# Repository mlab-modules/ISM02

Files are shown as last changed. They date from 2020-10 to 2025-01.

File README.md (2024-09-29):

# ISM02 - Long Range, Low Power, sub-GHz RF Transceiver

ISM02A is a telemetry module based on the Semtech SX1262 RF transceiver. This module is widely used in LoRa and other sub-GHz wireless communication applications. It incorporates an RF switch (PE4259) to multiplex RX and TX on a single antenna, making it a compact solution for IoT and telemetry use cases.

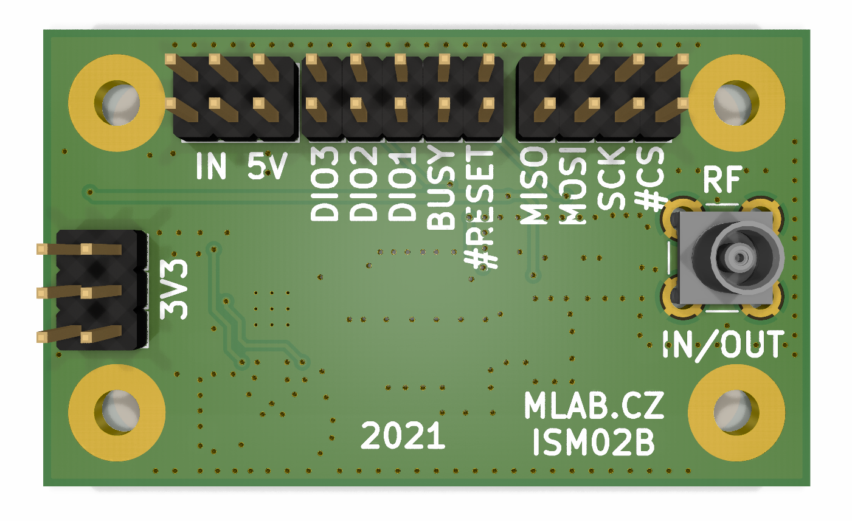
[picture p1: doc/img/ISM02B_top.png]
ISM02A Top

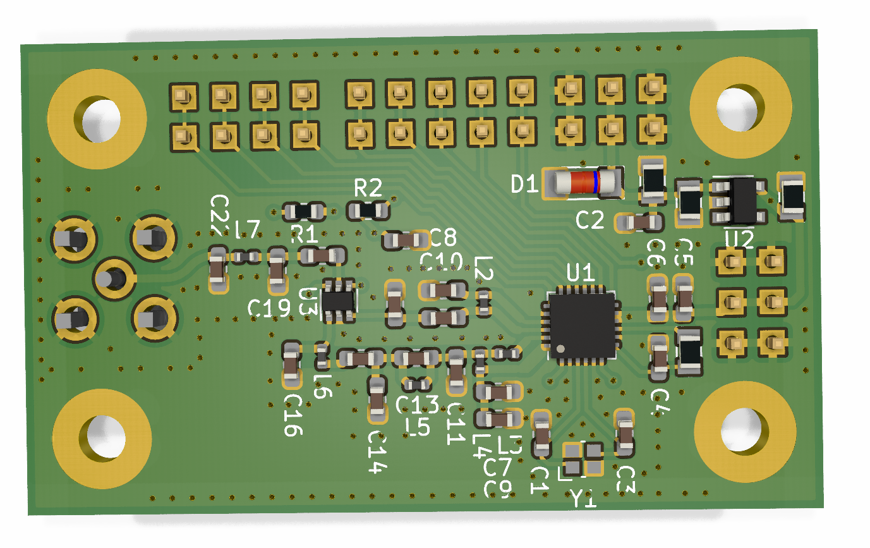
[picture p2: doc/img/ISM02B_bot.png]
ISM02A Bottom


## Features
- **RF Transceiver:** [SX1262](https://www.semtech.com/products/wireless-rf/lora-transceivers/sx1262)
  - More power-efficient compared to the SX127x series
  - Additional features with a smaller footprint and fewer external components
  - Operating frequency range: 150 MHz to 960 MHz
  - Supports LoRa and (G)FSK modulation
  - Maximum output power: +22 dBm
  - Low power consumption: 4.2 mA in receive mode
  - Complies with ETSI EN 300 220, FCC CFR 47 Part 15, and other global ISM band regulations
- **RF Switch:** [PE4259](https://www.psemi.com/products/rf-switches/pe4259) UltraCMOS RF switch
  - Frequency range: 10 MHz – 3000 MHz
  - Low insertion loss: 0.35 dB @ 1000 MHz
  - High isolation: 30 dB @ 1000 MHz
  - High ESD tolerance of 2 kV HBM
  - Used to multiplex RX and TX on a single antenna

The module is typically used as a LoRa device and offers flexible wireless communication for various low-power, long-range applications.

## Applications
- Remote sensors
- Agricultural sensors
- HAB/stratospheric balloon tracking and telemetry
- Remote control applications (UAVs, Robots)

## Specifications

| Parameter | Value | Description |
|---|---|---|
| Dimensions | 50.292 x 29.972 mm | Physical size of the module |
| Frequency Range | 150 MHz – 960 MHz | Supports sub-GHz ISM bands |
| Modulation Types | LoRa, FSK | Supports LoRaWAN and proprietary |
| Max Output Power | +22 dBm | Using SX1262 |
| Power Consumption  | 4.2 mA in Rx mode | Low power consumption |
| RF Switch | PE4259 | Used for antenna multiplexing |

## Additional Resources
- [SX1262 Datasheet](https://www.semtech.com/products/wireless-rf/lora-transceivers/sx1262)
- [PE4259 Datasheet](https://www.psemi.com/products/rf-switches/pe4259)

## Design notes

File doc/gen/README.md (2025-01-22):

# PCB

Board size: 50.29x29.97 mm (1.98x1.18 inches)

- This is the size of the rectangle that contains the board
- Thickness: 1.6 mm (63 mils)
- Material: FR4
- Finish: None
- Layers: 2
- Copper thickness: 35 µm

Solder mask: TOP / BOTTOM

- Color: Green

Silk screen: TOP / BOTTOM

- Color: White

Stackup:

| Name | Type | Color | Thickness [µm]| Material | Er | Loss tan |
|---|---|---|---|---|---|---|
| F.SilkS | Top Silk Screen | | | | | |
| F.Paste | Top Solder Paste | | | | | |
| F.Mask | Top Solder Mask | Green | 10 | | | |
| F.Cu | copper | | 35 | | | |
| dielectric 1 | core | | 1510 | FR4 | 4.5 | 0.020 |
| B.Cu | copper | | 35 | | | |
| B.Mask | Bottom Solder Mask | Green | 10 | | | |
| B.Paste | Bottom Solder Paste  | | | | | |
| B.SilkS | Bottom Silk Screen | | | | | |

# Important sizes

Clearance: 0.25 mm (10 mils)

Track width: 0.25 mm (10 mils)

- By design rules: 0.2 mm (8 mils)

Drill: 0.3 mm (12 mils)

- Vias: 0.4 mm (16 mils) [Design: 0.4 mm (16 mils)]
- Pads: 0.3 mm (12 mils)
- The above values are real drill sizes, they add 0.1 mm (4 mils) to plated holes (PTH)

Via: 0.6/0.3 mm (24/12 mils)

- By design rules: 0.4/0.3 mm (16/12 mils)
- Micro via: yes [0.2/0.1 mm (8/4 mils)]
- Buried/blind via: yes
- Total: 194 (thru: 194 buried/blind: 0 micro: 0)

Outer Annular Ring: 0.1 mm (4 mils)

- By design rules: 0.1 mm (4 mils)

Eurocircuits class: 6D
- Using min drill 0.25 mm for an OAR of 0.13 mm

# General stats

Components count: (SMD/THT)

- Top: 0/18 (THT)
- Bottom: 37/0 (SMD)

Defined tracks:

Used tracks:

- 0.25 mm (10 mils) (205) defined: no
- 0.3 mm (12 mils) (21) defined: no
- 0.4 mm (16 mils) (1) defined: no
- 0.5 mm (20 mils) (89) defined: no

Defined vias:

Used vias:

- 0.6/0.3 mm (24/12 mils) (Count: 194, Aspect: 2.7 A) defined: no

Holes (excluding vias):

- 0.2 mm (8 mils) (9)
- 0.89 mm (35 mils) (30)
- 1.5 mm (59 mils) (1)
- 1.7 mm (67 mils) (4)
- 3.0 mm (118 mils) (4)

Oval holes:

Drill tools (including vias and computing adjusts and rounding):

- 0.3 mm (12 mils) (9)
- 0.4 mm (16 mils) (194)
- 1.0 mm (39 mils) (30)
- 1.6 mm (63 mils) (1)
- 1.8 mm (71 mils) (4)
- 3.1 mm (122 mils) (4)

Solder paste stats:

Using a paste with 87.75 % alloy, that has an specific gravity for the alloy of 7.4 g/cm³
and 1.0 g/cm³ for the flux. This paste has an specific gravity of  4.15 g/cm³.

The stencil thickness is  0.12 mm.

| Side | Pads with paste | Area [mm²] | Paste [g] |
|---|---|---|---|
| Total  | 109 | 76.86 | 0.38 |

Note: this is just an approximation to the theoretical value. Margins of the solder mask and waste aren't computed.

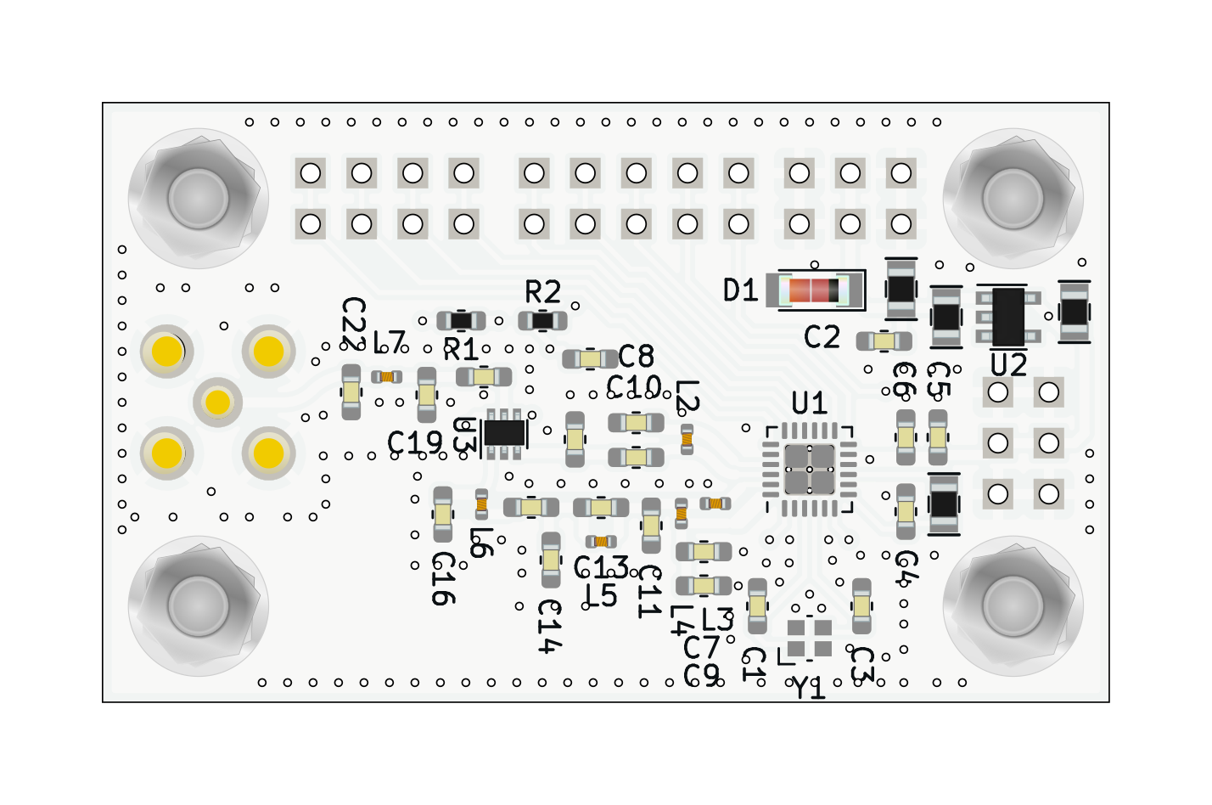
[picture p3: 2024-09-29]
doc/gen/img/ISM02-bottom.png

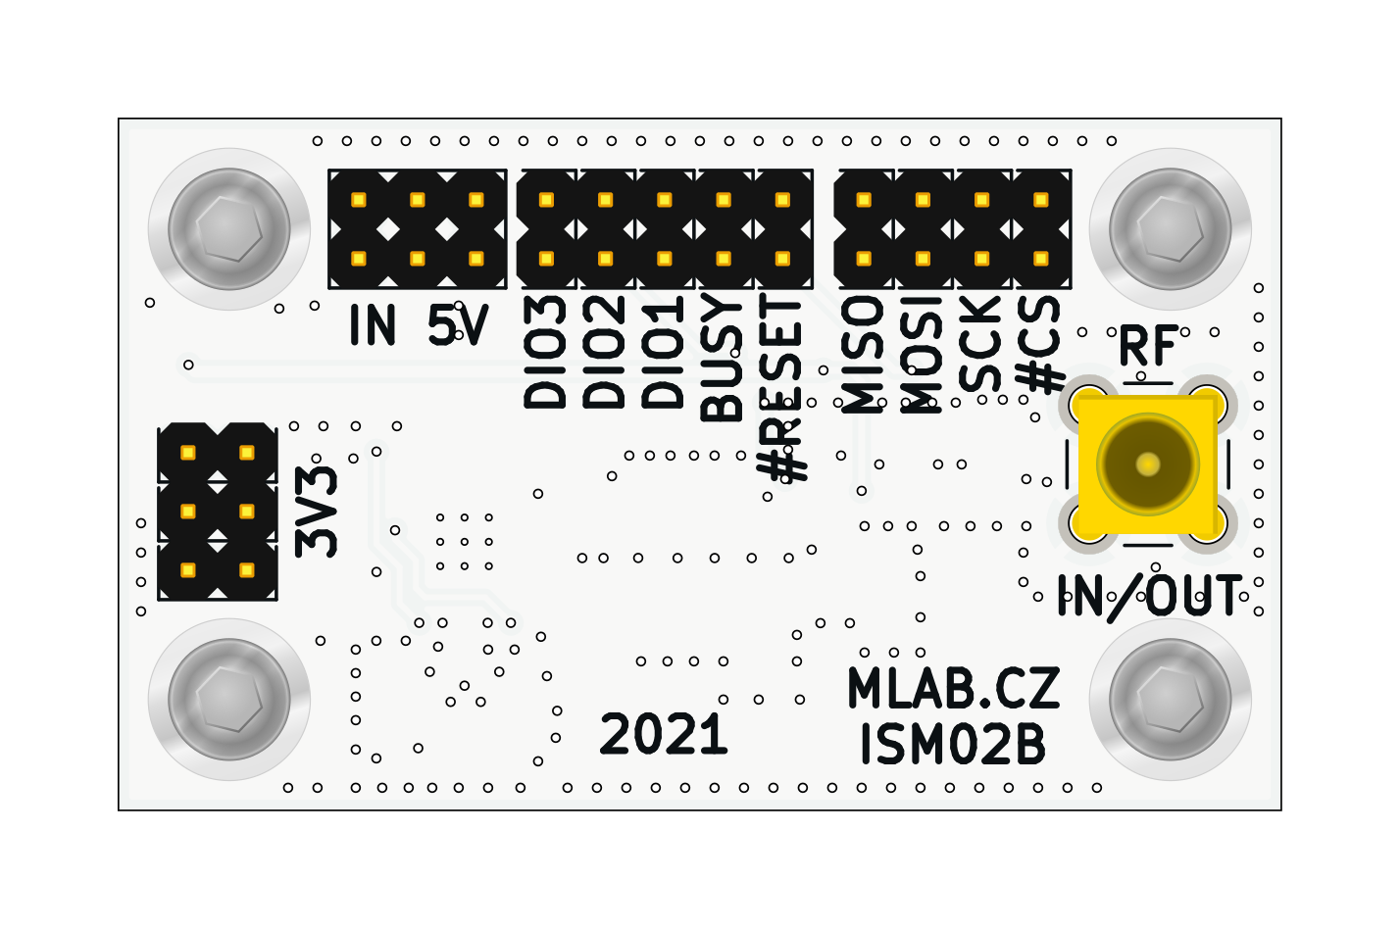
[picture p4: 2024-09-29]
doc/gen/img/ISM02-top.png

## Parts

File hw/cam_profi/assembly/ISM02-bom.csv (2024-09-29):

Component | Description | Part | References | Value | Footprint | Quantity Per PCB | Datasheet | mfpn | ust_id
1 |  | C-Device-ISM02A-rescue | C8 | 1p8 | C_0603_1608Metric_Pad1.05x0.95mm_HandSolder | 1 |  | C0G 0,1pF 50V | 5dad52a4128750448eca18e8
2 |  | C-Device-ISM02A-rescue | C16 | 2p2 | C_0603_1608Metric_Pad1.05x0.95mm_HandSolder | 1 |  | C0G 0,1pF 50V | 5c70984812875079b91f8bdd
3 |  | C-Device-ISM02A-rescue | C10 | 2p4 | C_0603_1608Metric_Pad1.05x0.95mm_HandSolder | 1 |  | C0G 0,1pF 50V | 5dad53d8128750448eca1906
4 |  | C-Device-ISM02A-rescue | C13C19C22 | 3p3 | C_0603_1608Metric_Pad1.05x0.95mm_HandSolder | 3 |  | C0G 0,1pF 50V | 5cd09016128750448e45434f
5 |  | C-Device-ISM02A-rescue | C14 | 5p6 | C_0603_1608Metric_Pad1.05x0.95mm_HandSolder | 1 |  | C0G 0,25pF 50V | 5dad5450128750448eca1919
6 |  | C-Device-ISM02A-rescue | C15C17 | 39pF | C_0603_1608Metric_Pad1.05x0.95mm_HandSolder | 2 |  | C0G 5% 50V | 5dad549f128750448eca1926
7 |  | C-Device-ISM02A-rescue | C9 | 47pF | C_0603_1608Metric_Pad1.05x0.95mm_HandSolder | 1 |  | C0G 5% 50V | 5dad5314128750448eca18f7
8 | Unpolarized capacitor | C | C18 | 1nF | C_0603_1608Metric_Pad1.05x0.95mm_HandSolder | 1 | ~ |  | 5c70984812875079b91f8bec
9 |  | C-Device-ISM02A-rescue | C7 | 47nF | C_0603_1608Metric_Pad1.05x0.95mm_HandSolder | 1 |  | X7R 1% 16V | 5dad51cf128750448eca18d8
10 |  | C_Small-Device-ISM02A-rescue | C2 | 100nF | C_0603_1608Metric_Pad1.05x0.95mm_HandSolder | 1 |  |  | C0805_100n
11 |  | C-Device-ISM02A-rescue | C6 | 100nF | C_0603_1608Metric_Pad1.05x0.95mm_HandSolder | 1 |  |  | 5c70984812875079b91f8bf2
12 |  | C-Device-ISM02A-rescue | C4 | 470nF | C_0603_1608Metric_Pad1.05x0.95mm_HandSolder | 1 |  | X5R 10% 10V | 5dad50c1128750448eca18c6
13 |  | C-Device-ISM02A-rescue | C5 | 1uF | C_0603_1608Metric_Pad1.05x0.95mm_HandSolder | 1 |  |  | 5c70984812875079b91f8bc2
14 |  | C_Small-Device-ISM02A-rescue | C21C24C25 | 10uF | SMD-0805 | 3 |  |  | 5c70984812875079b91f8bbe
15 |  | C-Device-ISM02A-rescue | C1C3C11C12 | - | C_0603_1608Metric_Pad1.05x0.95mm_HandSolder | 4
16 |  | D_ZENER-MLAB_D | D1 | BZV55C-5,6V | Diode-MiniMELF_Standard | 1 |  |  | 5c70984512875079b91f88b2
17 |  | HEADER_2x01_PARALLEL-MLAB_HEADER | J2J3J4J5J6J7J8J9J10J11J13J15 | HEADER_2x01_PARALLEL | Straight_2x01 | 12
18 |  | JUMP_3X2-MLAB_Jumpers | J1 | JUMP_3X2 | Straight_2x03 | 1
19 |  | SMA-MLAB_CONNECTORS | J12 | MCX | MCX | 1
20 |  | L-Device-ISM02A-rescue | L3 | 0R | L_0402_1005Metric | 1 |  |  | 5c70984512875079b91f8949
21 |  | L-Device-ISM02A-rescue | L5 | 2n5 | L_0402_1005Metric | 1 |  | LQW15AN2N5C00D | 5dad56ff128750448eca1975
22 |  | L-Device-ISM02A-rescue | L6 | 4n7 | L_0402_1005Metric | 1 |  | LQW15AN4N7C00D | 5dad574f128750448eca1986
23 |  | L-Device-ISM02A-rescue | L7 | 9n1 | L_0402_1005Metric | 1 |  | LQW15AN9N1H00D | 5dad5789128750448eca1995
24 |  | L-Device-ISM02A-rescue | L2 | 15nH | L_0402_1005Metric | 1 |  | LQW15AN15NH00D | 5dad566c128750448eca1959
25 |  | L-Device-ISM02A-rescue | L4 | 47nH | L_0402_1005Metric | 1 |  | LQW15AN47NJ00D | 5dad56ba128750448eca1968
26 |  | L_Small-Device-ISM02A-rescue | L1 | 15uH | SMD-0805 | 1 |  | MLZ2012M150W 0805 | 5dad55e8128750448eca1941
27 | Resistor | R | R2 | 100R | SMD-0603 | 1 | ~ |  | 5c70984512875079b91f8956
28 |  | R-Device-ISM02A-rescue | R1 | 10k | SMD-0603 | 1 |  |  | 5c70984512875079b91f8962
29 |  | MIC5504-3.3YM5-Regulator_Linear-ISM02A-rescue | U2 | MIC5504-3.3YM5 | SOT-23-5 | 1 | http://ww1.microchip.com/downloads/en/DeviceDoc/MIC550X.pdf |  | 5c7255e81287500b4e112ea2
30 | RF Switch | PE4259 | U3 | PE4259 | SOT-363_SC-70-6 | 1 | https://www.psemi.com/pdf/datasheets/pe4259ds.pdf |  | 5face19b12875025b3977e15
31 |  | SX1262-MLAB_IO-ISM02A-rescue | U1 | SX1262 | QFN-24-1EP_4x4mm_P0.5mm_EP2.6x2.6mm_ThermalVias | 1 |  |  | 5dad5866128750448eca19a4
32 |  | Crystal_GND24-Device-ISM02A-rescue | Y1 | 32MHz | Crystal_SMD_NX2016SA | 1 |  | NX2016SA-32M-EXS00A-CS06465 | 5dad592b128750448eca19b2

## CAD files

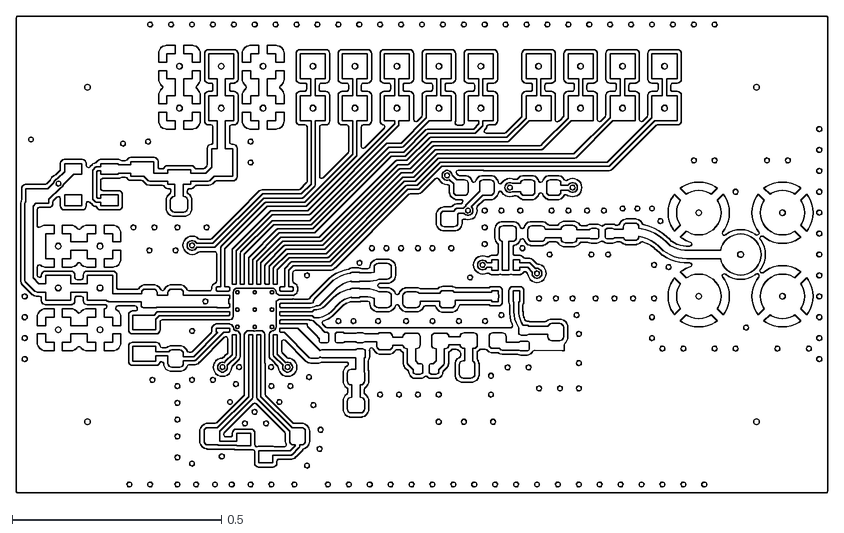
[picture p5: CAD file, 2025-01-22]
doc/gen/dxf/ISM02-B_Cu.dxf
1.94 x 1.14

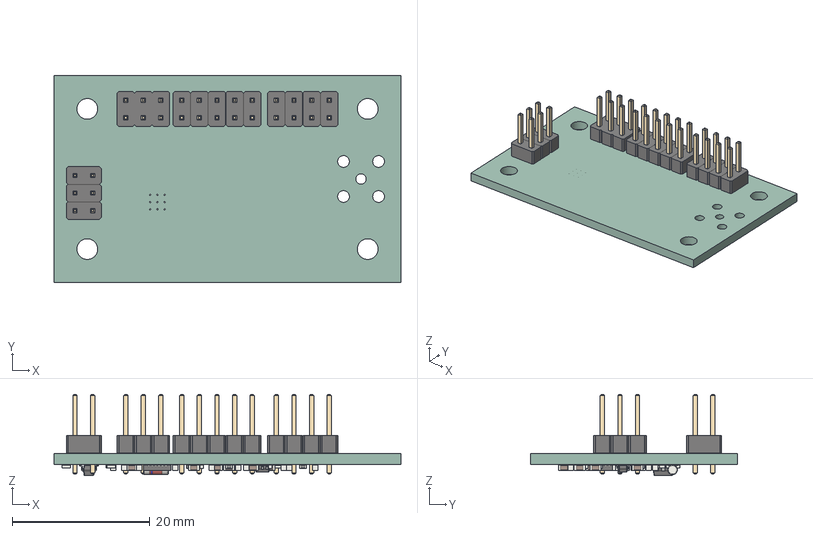
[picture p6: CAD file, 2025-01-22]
doc/gen/ISM02.step
50.3 x 30.0 x 11.8 mm
PinHeader_2x01_P254mm_Vertical x 12
PinHeader_2x03_P254mm_Vertical
C_0603_1608Metric x 20
QFN-24-1EP_4x4mm_Pitch0.5mm
R_0603_1608Metric x 2
L_0402_1005Metric x 6
R_0805_2012Metric x 4
D_MiniMELF_Standard
SOT_23_5
SOT_363_SC_70_6
kibot_rq6rvf45_PCB

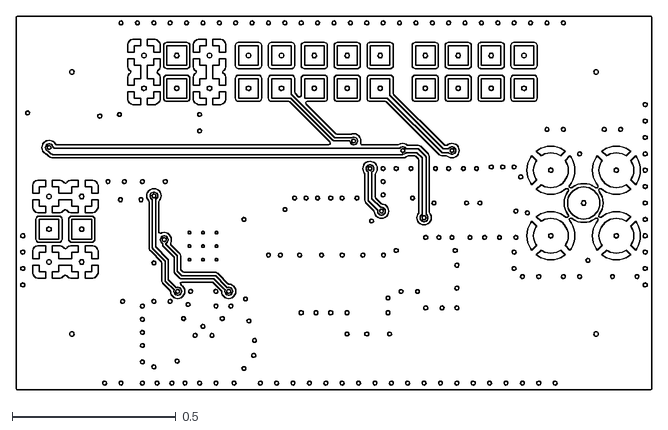
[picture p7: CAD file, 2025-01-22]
doc/gen/dxf/ISM02-F_Cu.dxf
1.94 x 1.14

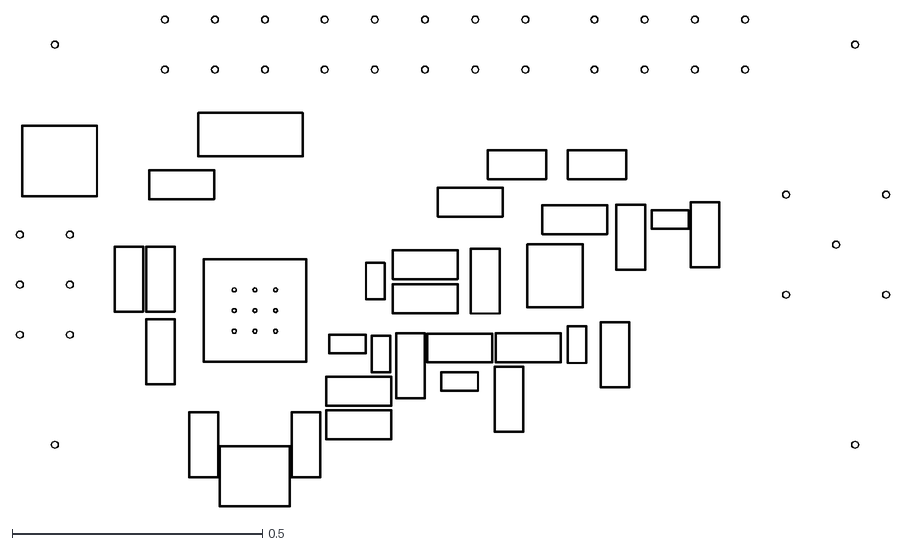
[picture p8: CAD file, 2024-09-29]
doc/gen/dxf/ISM02-B_Courtyard.dxf
1.75 x 0.981

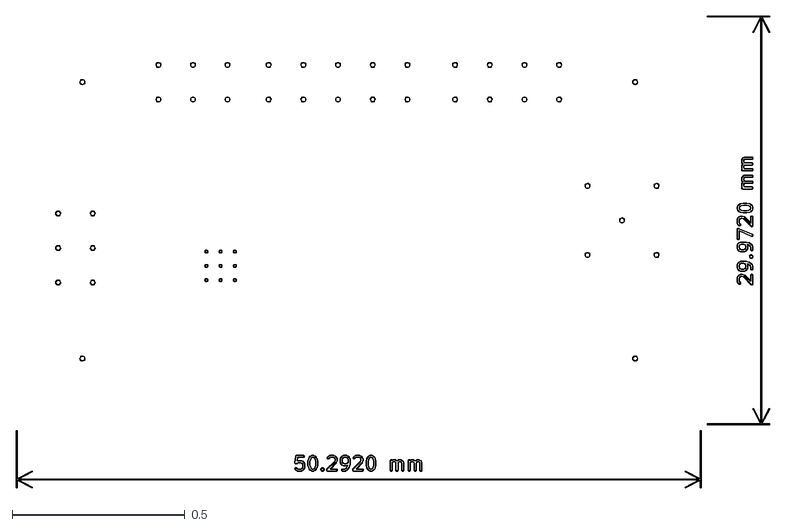
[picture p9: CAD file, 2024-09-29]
doc/gen/dxf/ISM02-F_Courtyard.dxf
2.18 x 1.37

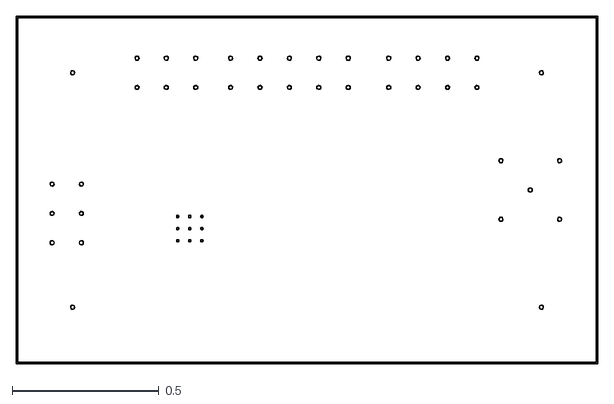
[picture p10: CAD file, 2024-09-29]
doc/gen/dxf/ISM02-Edge_Cuts.dxf
1.99 x 1.19

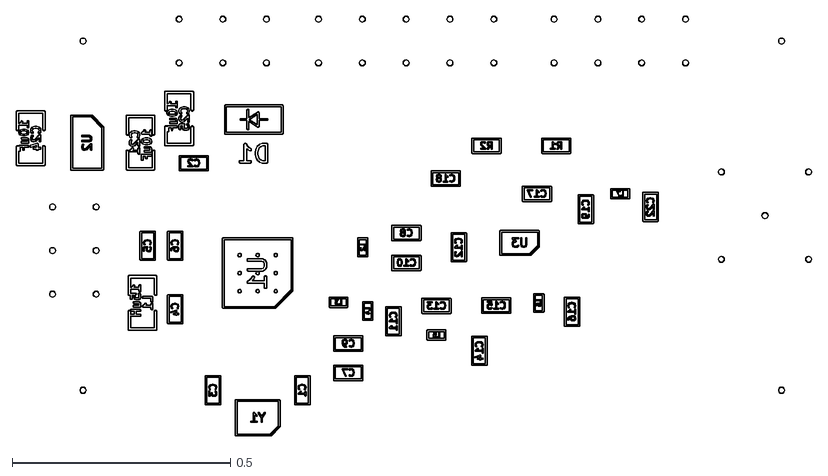
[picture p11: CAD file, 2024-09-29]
doc/gen/dxf/ISM02-B_Fab.dxf
1.82 x 0.961

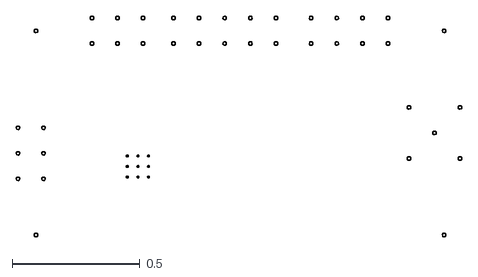
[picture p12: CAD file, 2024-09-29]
doc/gen/dxf/ISM02-Margin.dxf
1.75 x 0.864

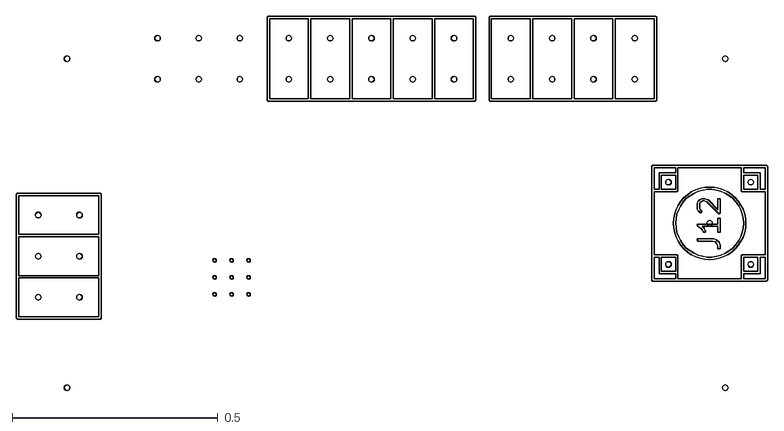
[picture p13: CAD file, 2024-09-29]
doc/gen/dxf/ISM02-F_Fab.dxf
1.83 x 0.91

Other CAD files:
doc/gen/dxf/ISM02-B_Mask.dxf
doc/gen/dxf/ISM02-B_Paste.dxf
doc/gen/dxf/ISM02-B_Silkscreen.dxf
doc/gen/dxf/ISM02-F_Mask.dxf
doc/gen/dxf/ISM02-F_Paste.dxf
doc/gen/dxf/ISM02-F_Silkscreen.dxf

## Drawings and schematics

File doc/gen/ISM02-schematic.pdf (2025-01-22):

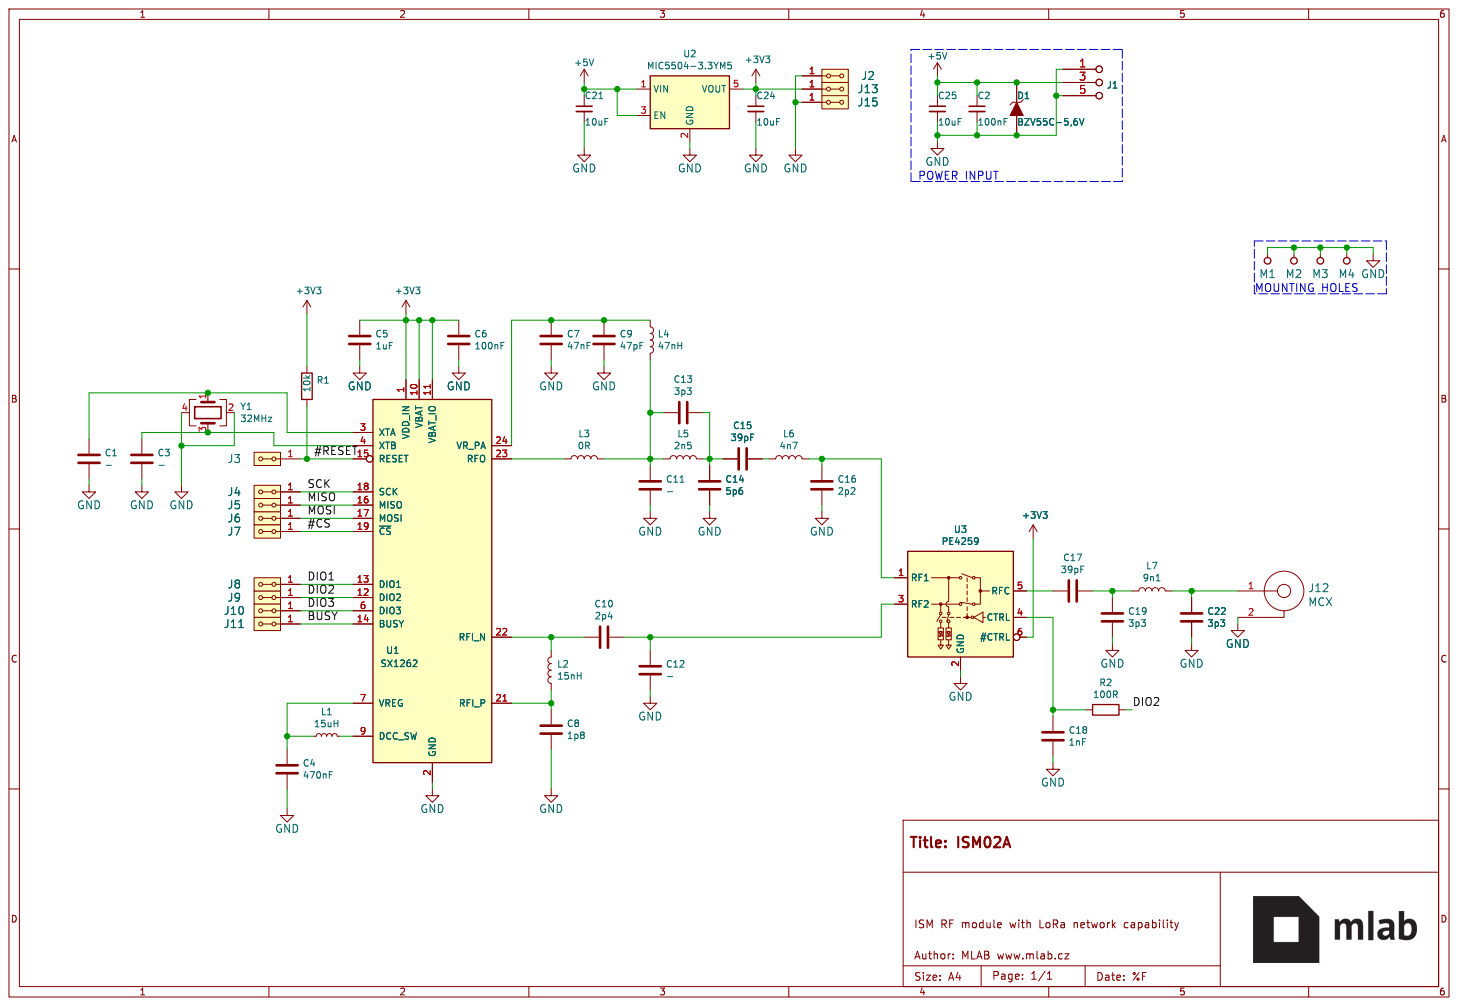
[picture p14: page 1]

1 VBAT 10 VBAT_IO 11 DIO2 12 DIO1 13 BUSY 14 RESET 15 MISO 16 MOSI 17 SCK 18 ~{CS} 19 GND

2 RFI_P 21 RFI_N 22 RFO 23 VR_PA 24 XTA 3 XTB 4 DIO3 6 VREG 7 DCC_SW 9 U1 SX1262

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

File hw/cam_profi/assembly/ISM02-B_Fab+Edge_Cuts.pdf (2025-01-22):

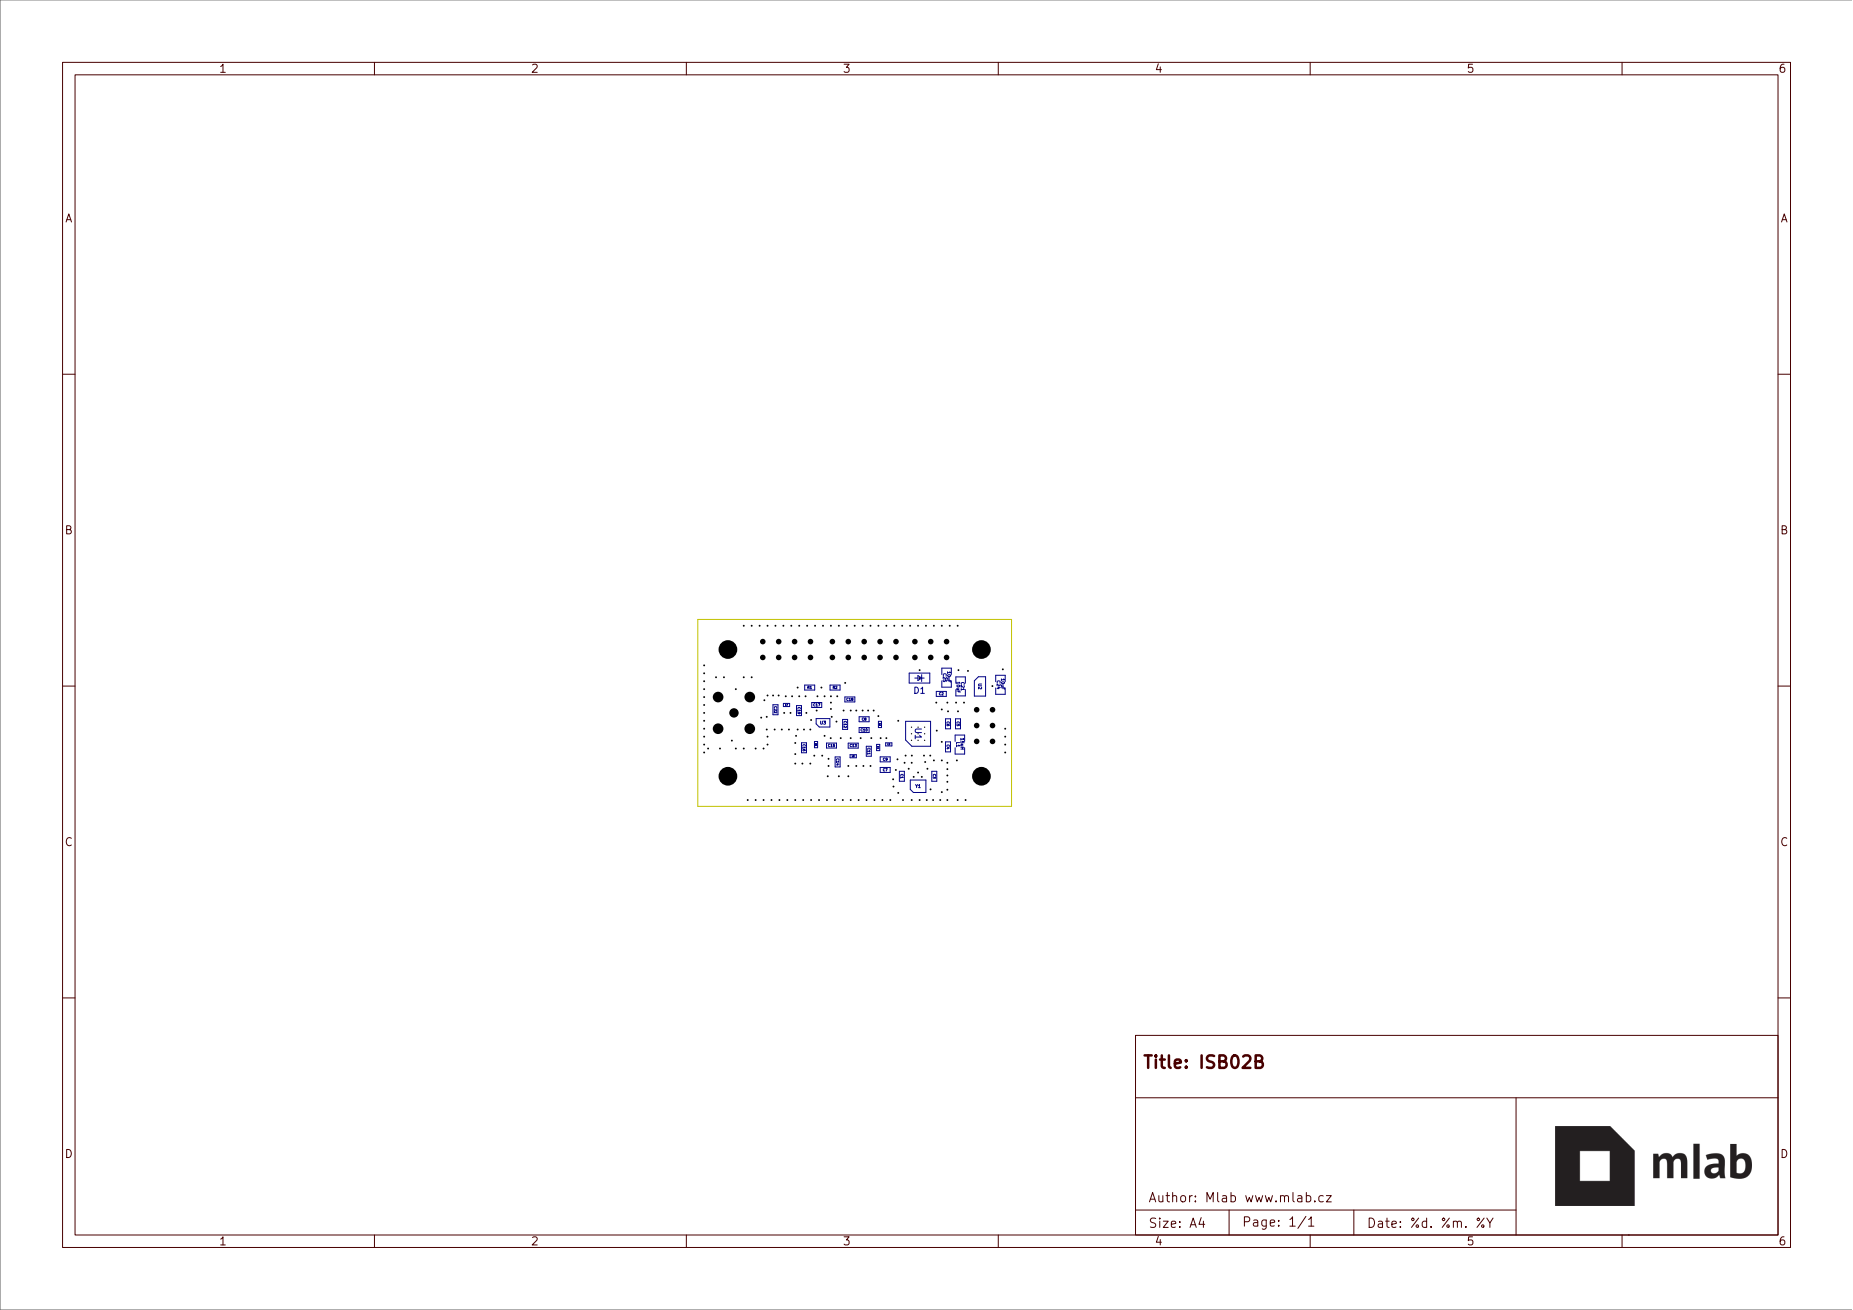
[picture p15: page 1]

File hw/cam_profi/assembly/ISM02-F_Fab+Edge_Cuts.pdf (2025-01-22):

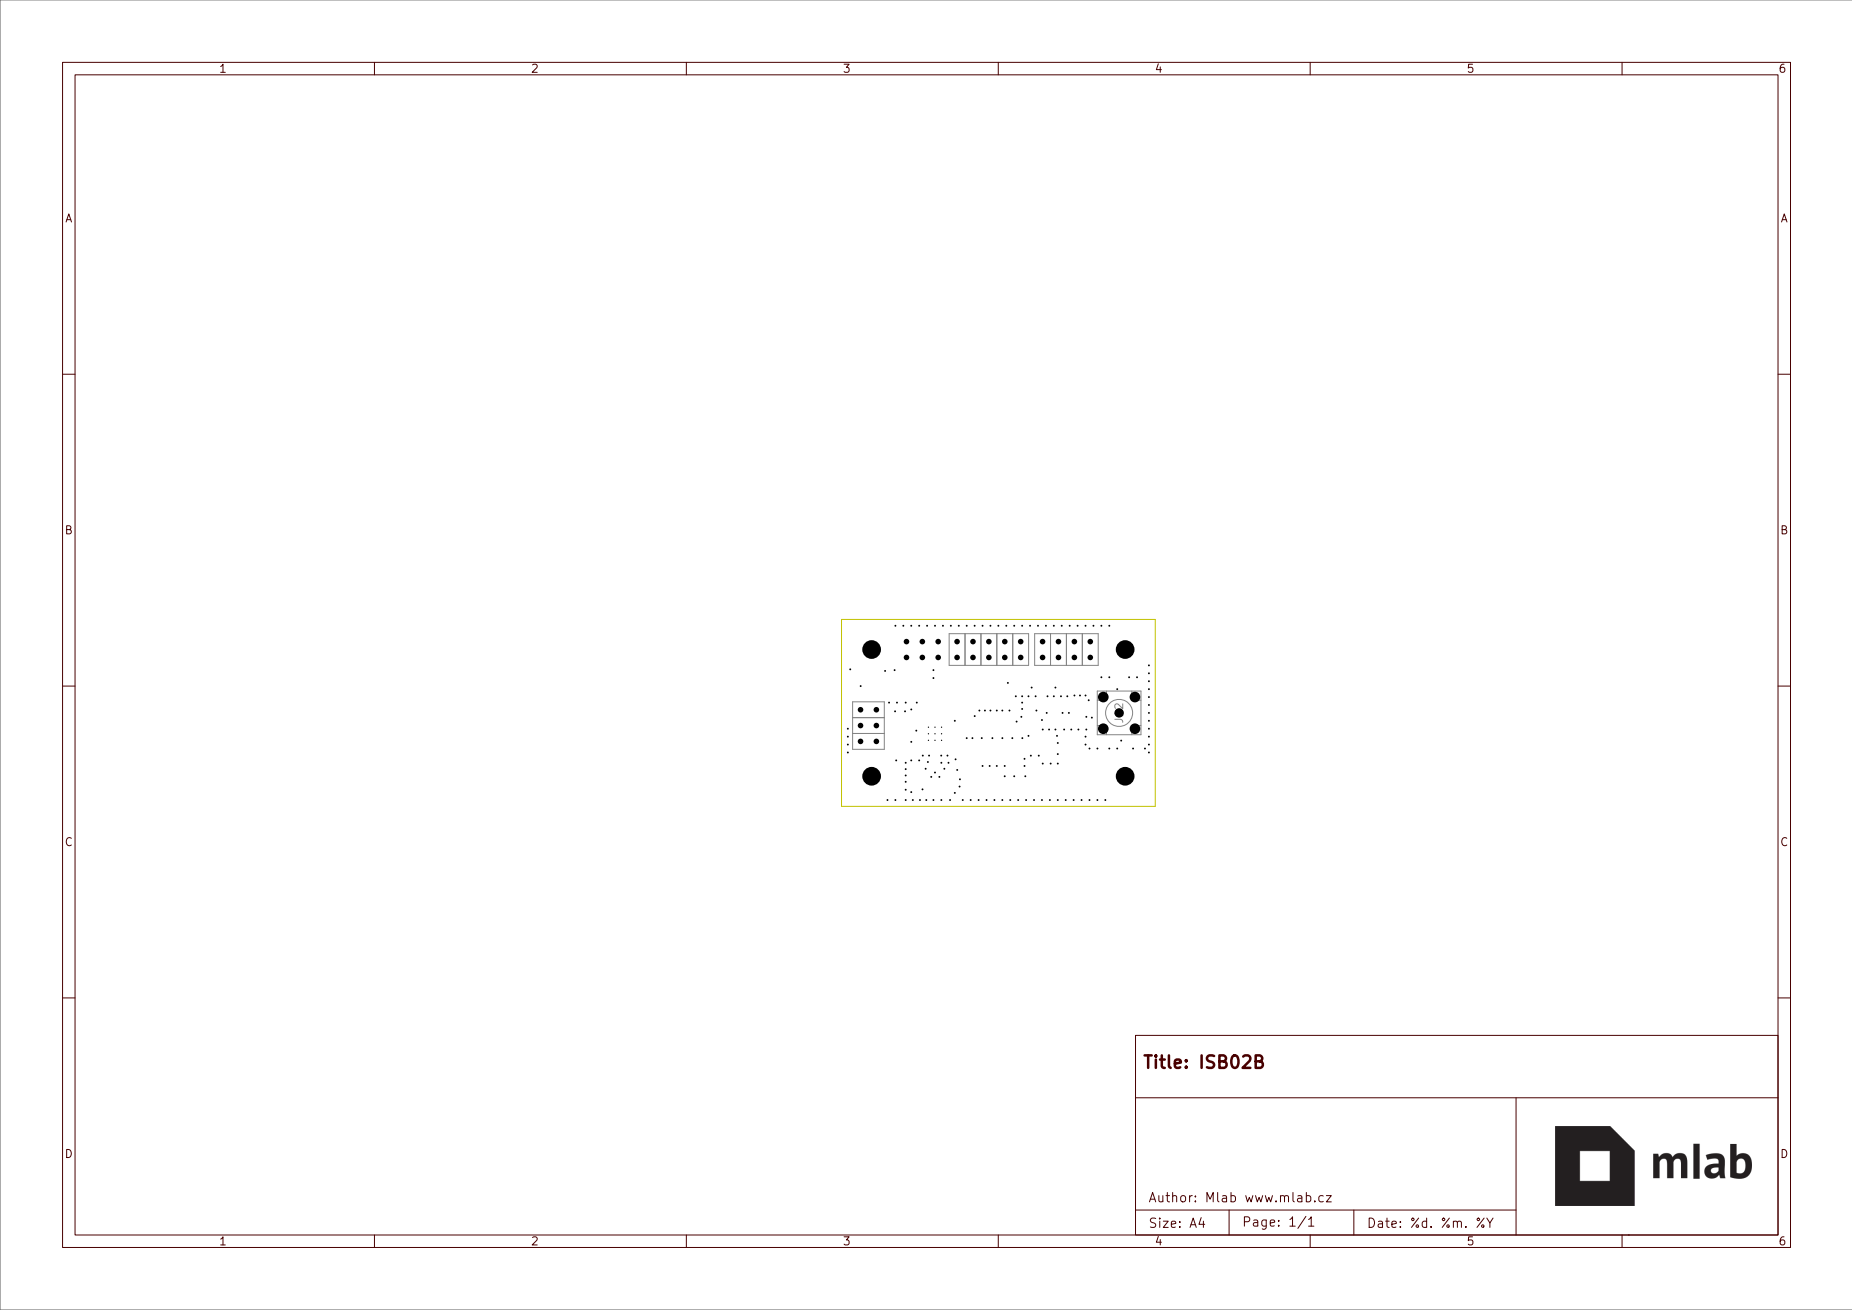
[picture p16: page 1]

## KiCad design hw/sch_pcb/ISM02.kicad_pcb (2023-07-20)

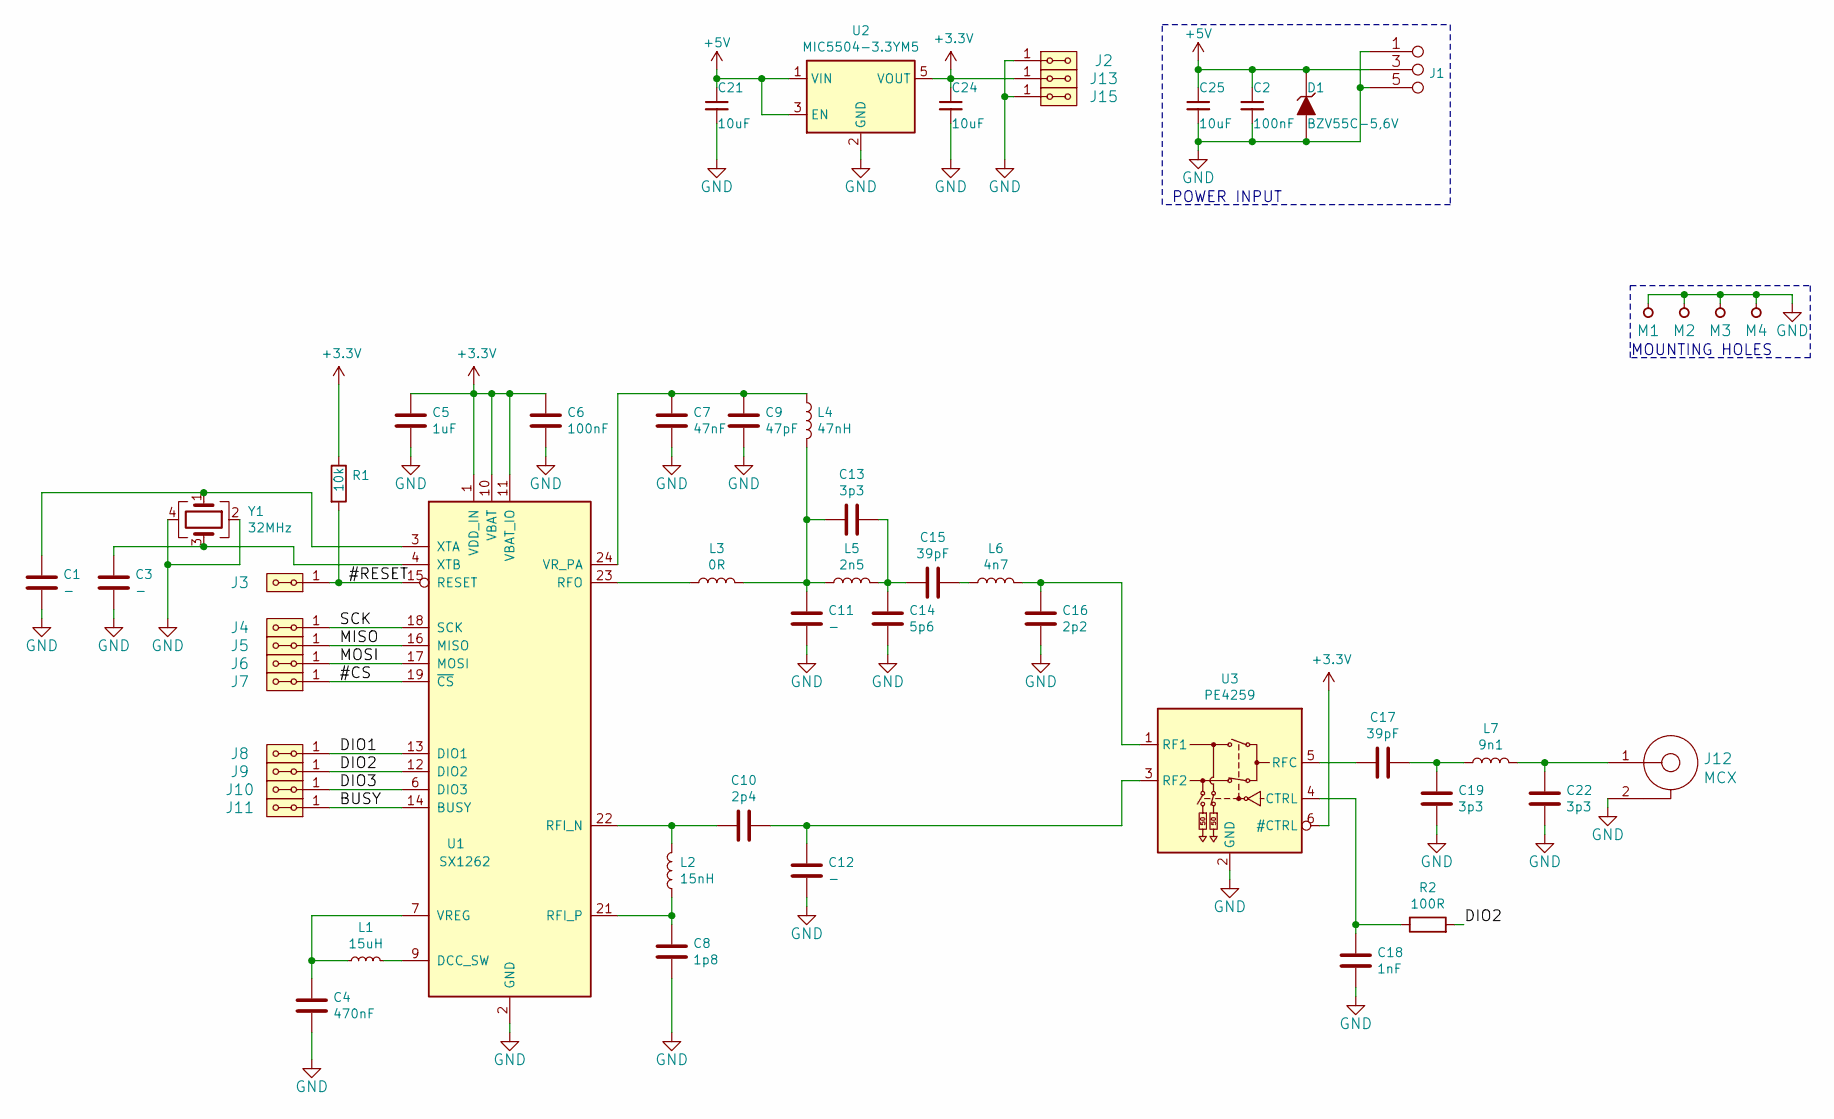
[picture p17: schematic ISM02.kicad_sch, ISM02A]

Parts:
C1, C3, C11, C12: -; C_0603_1608Metric_Pad1.05x0.95mm_HandSolder
C2, C6: 100nF; C_0603_1608Metric_Pad1.05x0.95mm_HandSolder
C4: 470nF; C_0603_1608Metric_Pad1.05x0.95mm_HandSolder
C5: 1uF; C_0603_1608Metric_Pad1.05x0.95mm_HandSolder
C7: 47nF; C_0603_1608Metric_Pad1.05x0.95mm_HandSolder
C8: 1p8; C_0603_1608Metric_Pad1.05x0.95mm_HandSolder
C9: 47pF; C_0603_1608Metric_Pad1.05x0.95mm_HandSolder
C10: 2p4; C_0603_1608Metric_Pad1.05x0.95mm_HandSolder
C13, C19, C22: 3p3; C_0603_1608Metric_Pad1.05x0.95mm_HandSolder
C14: 5p6; C_0603_1608Metric_Pad1.05x0.95mm_HandSolder
C15, C17: 39pF; C_0603_1608Metric_Pad1.05x0.95mm_HandSolder
C16: 2p2; C_0603_1608Metric_Pad1.05x0.95mm_HandSolder
C18: 1nF; C_0603_1608Metric_Pad1.05x0.95mm_HandSolder
C21, C24, C25: 10uF; SMD-0805
D1: BZV55C-5,6V; Diode-MiniMELF_Standard
J1: JUMP_3X2; Straight_2x03
J2, J3, J4, J5, J6, J7, J8, J9, J10, J11, J13, J15: HEADER_2x01_PARALLEL; Straight_2x01
J12: MCX
L1: 15uH; SMD-0805
L2: 15nH; L_0402_1005Metric
L3: 0R; L_0402_1005Metric
L4: 47nH; L_0402_1005Metric
L5: 2n5; L_0402_1005Metric
L6: 4n7; L_0402_1005Metric
L7: 9n1; L_0402_1005Metric
M1, M2, M3, M4: HOLE; MountingHole_3mm
R1: 10k; SMD-0603
R2: 100R; SMD-0603
U1: SX1262; QFN-24-1EP_4x4mm_P0.5mm_EP2.6x2.6mm_ThermalVias
U2: MIC5504-3.3YM5; SOT-23-5
U3: PE4259; SOT-363_SC-70-6
Y1: 32MHz; Crystal_SMD_NX2016SA

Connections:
+3V3: C5.1, C6.1, C24.1, J13.1, J13.2, R1.1, U1.1 (VDD_IN), U1.10 (VBAT), U1.11 (VBAT_IO), U2.5 (VOUT), U3.6 (#CTRL)
+5V: C2.1, C21.1, C25.1, D1.1 (K), J1.3 (4), J1.4, U2.1 (VIN), U2.3 (EN)
/#CS: J7.1, J7.2, U1.19 (~CS~)
/#RESET: J3.1, J3.2, R1.2, U1.15 (RESET)
/BUSY: J11.1, J11.2, U1.14 (BUSY)
/DIO1: J8.1, J8.2, U1.13 (DIO1)
/DIO2: J9.1, J9.2, R2.2, U1.12 (DIO2)
/DIO3: J10.1, J10.2, U1.6 (DIO3)
/MISO: J5.1, J5.2, U1.16 (MISO)
/MOSI: J6.1, J6.2, U1.17 (MOSI)
/SCK: J4.1, J4.2, U1.18 (SCK)
GND: C1.2, C2.2, C3.2, C4.2, C5.2, C6.2, C7.2, C8.2, C9.2, C11.2, C12.2, C14.2, C16.2, C18.2, C19.1, C21.2, C22.1, C24.2, C25.2, D1.2 (A), J1.1 (2), J1.2, J1.5 (6), J1.6, J2.1, J2.2, J12.2, J15.1, J15.2, M1.1, M2.1, M3.1, M4.1, U1.2 (GND), U1.5 (GND), U1.8 (GND), U1.20 (GND), U1.25 (GND), U2.2 (GND), U3.2 (GND), Y1.2, Y1.4
unnamed: C1.1, U1.3 (XTA), Y1.1
unnamed: C3.1, U1.4 (XTB), Y1.3
unnamed: C4.1, L1.1, U1.7 (VREG)
unnamed: C7.1, C9.1, L4.1, U1.24 (VR_PA)
unnamed: C8.1, L2.1, U1.21 (RFI_P)
unnamed: C10.1, C12.1, U3.3 (RF2)
unnamed: C10.2, L2.2, U1.22 (RFI_N)
unnamed: C11.1, C13.2, L3.2, L4.2, L5.1
unnamed: C13.1, C14.1, C15.2, L5.2
unnamed: C15.1, L6.1
unnamed: C16.1, L6.2, U3.1 (RF1)
unnamed: C17.1, C19.2, L7.1
unnamed: C17.2, U3.5 (RFC)
unnamed: C18.1, R2.1, U3.4 (CTRL)
unnamed: C22.2, J12.1, L7.2
unnamed: L1.2, U1.9 (DCC_SW)
unnamed: L3.1, U1.23 (RFO)

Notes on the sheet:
MOUNTING HOLES
POWER INPUT

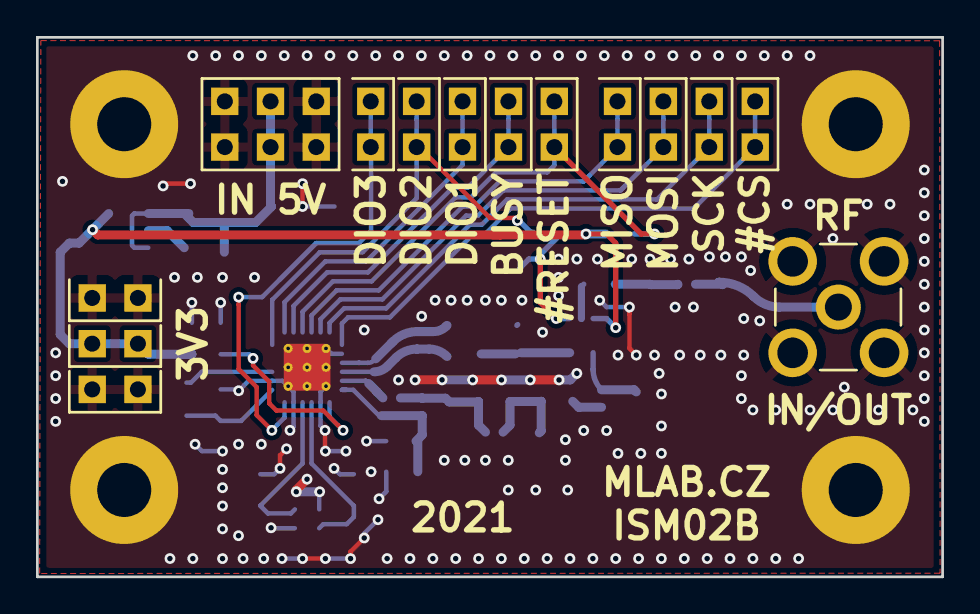
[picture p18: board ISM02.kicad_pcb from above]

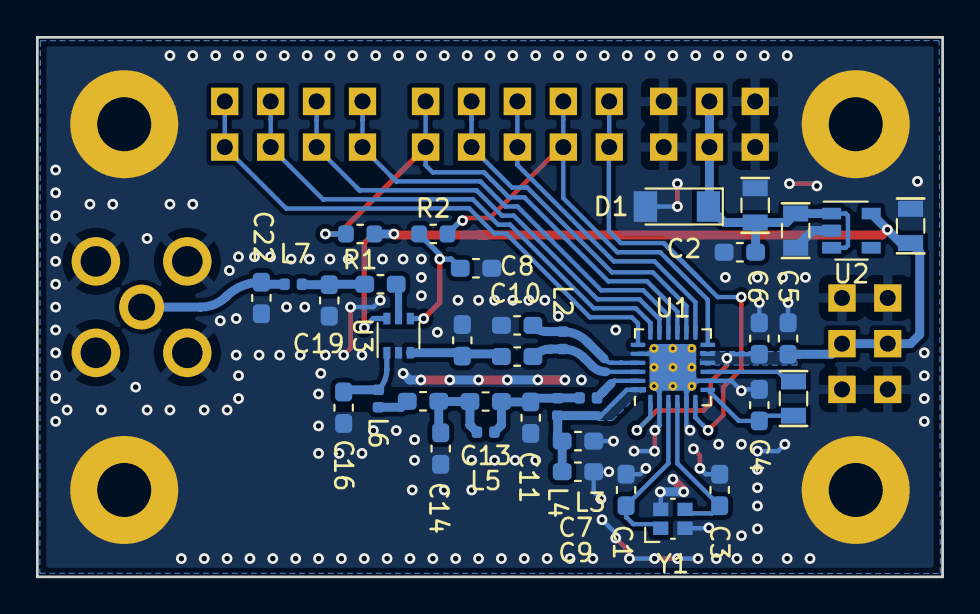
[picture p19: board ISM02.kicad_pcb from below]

Board: 2 copper layers, 50.3 x 30.0 mm, 55 parts (37 on the bottom side), 29 nets.

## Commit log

2019-10-10 [MLABweb] Documentation edits; ISM02A
    [ISM02A.kicad_pcb, ISM02A.sch]
2019-10-14 ISM02A edit schema
    [ISM02A.sch]
2019-10-16 ISM02 - edit schema
    [ISM02A.sch]
2019-10-18 ISM02A schema
    [ISM02A.sch]
2019-10-28 Prvni verze layoutu
    [ISM02A.kicad_pcb, ISM02A.sch]
2019-11-05 Pridana stinici krabicka, upravene rozmery, pridane prokovy
    [ISM02A.kicad_pcb, ISM02A.sch]
2019-11-08 Generovana vyrobni data
    [ISM02A-B_Cu.gbr, ISM02A-B_Mask.gbr, ISM02A-Edge_Cuts.gbr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]
2019-11-14 Uprava dat pro osazovani
    [ISM02A.kicad_pcb]
2020-10-28 Documentation improvement.
    [ISM02A.kicad_pcb, ISM02A.kicad_sch, ISM02A.sch]
2020-10-28 Update schematics export and crop images.
    [ISM02A.kicad_sch]
2021-03-23 Edit 02B
    [ISM02B.kicad_pcb, ISM02B.kicad_sch]
2021-03-25 Remove unused 1 mark from power connector.
    [ISM02B.kicad_pcb]
2022-04-06 Update actions products
    [ISM02B-B_Cu.gbr, ISM02B-B_Mask.gbr, ISM02B-Edge_Cuts.gbr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]
2023-02-13 resave in newer kicad
    [ISM02B.kicad_pcb, ISM02B.kicad_sch]
2023-07-20 kicad 7
    [ISM02B.kicad_pcb, ISM02B.kicad_sch]
2023-07-20 follow new naming style
    [ISM02.kicad_pcb, ISM02.kicad_sch]
2024-09-29 Updating documentation and readme.
    [ISM02.kicad_sch]

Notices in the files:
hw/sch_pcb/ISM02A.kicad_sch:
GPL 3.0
